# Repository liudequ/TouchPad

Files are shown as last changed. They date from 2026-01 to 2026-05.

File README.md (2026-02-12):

# 仓库指南

## 项目结构与模块组织
这是一个 Arduino 草图集合仓库。所有可编译草图放在 `sketches/` 下，并按 `product/`、`tools/`、`experiments/` 分组，每个草图一个独立文件夹，且 `.ino` 文件名与文件夹名一致：

- `sketches/tools/blink/blink.ino`
- `sketches/tools/ps2_scan/ps2_scan.ino`
- `sketches/tools/hid_report_dump/hid_report_dump.ino`
- `sketches/experiments/two_finger_tuning/two_finger_tuning.ino`
- `sketches/tools/try_read_data/try_read_data.ino`
- `sketches/product/touchpad_hid_nrf/touchpad_hid_nrf.ino`
- `sketches/tools/touchpad_i2c_probe_nrf/touchpad_i2c_probe_nrf.ino`
- `sketches/tools/ble_conn_test/ble_conn_test.ino`
- `sketches/tools/ble_hid_rate_test/ble_hid_rate_test.ino`
- `sketches/tools/serial_alive_nicenano/serial_alive_nicenano.ino`
- `sketches/tools/led_test_nicenano/led_test_nicenano.ino`
- `sketches/tools/soft_switch_test/soft_switch_test.ino`

文档放在 `docs/`（索引见 `docs/README.md`）。每个草图自包含、互不依赖。
3D 模型放在 `models/`，用于外壳设计与打印参考。
制造资料入口见 `manufacturing/README.md`。

## 文档说明（docs）
- `docs/touchpad_usage.md`：nRF 触摸板使用说明（接线、烧录、操作、串口命令与 UI 配置）。
- `docs/arduino_ide_supermini_setup.md`：Arduino IDE 本地板卡配置与 UF2 刷写流程说明。
- `docs/ble_conn_test.md`：`ble_conn_test` 草图的人工测试步骤与预期结果。
- `docs/bluetooth_migration_notes.md`：蓝牙迁移历史记录与现状说明（含 BLE 抓包分析方法）。
- `docs/bom.md`：触摸板项目物料清单（BOM）与接线速查。
- `docs/video_intro_flow.md`：触摸板介绍视频的分段流程与口播参考。
- `docs/stability_tuning.md`：手感稳定性与防抖调参思路清单。
- `docs/fpc_pinout.md`：触摸板 FPC 转接板引脚定义（nRF 方案）。
- `docs/schematic_nice_nano_v2.png`：nice!nano v2 原理图参考图。
- `docs/Promicro NRF52840开发板 兼容nice!nano V2.0 带蓝牙 充电管理-淘宝网.png`：开发板商品页截图参考。
- `docs/nRF52840_PS_v1.1.pdf`：nRF52840 官方规格书（参考资料）。

## 模型说明（models）
- `models/touchpad_case.scad`：触摸板外壳 OpenSCAD 源文件。
- `models/touchpad_case.stl`：触摸板外壳可打印 STL 文件。
- `models/case_notes.md`：外壳设计与打印参数说明。
- 备注：当前 3D 模型较粗糙，主要用于尺寸与装配验证，实际空间有很大的冗余。

## 构建、测试与开发命令
当前推荐流程（nice!nano v2）：

1. 在 Arduino IDE 打开目标草图，执行“导出编译二进制文件”（Export Compiled Binary）。
2. 在仓库根目录运行：
   - `tools/make_uf2_latest_nicenano_v2.sh`
3. 脚本会基于最新导出的二进制生成对应 `.uf2` 文件。
4. 将生成的 `.uf2` 文件复制到开发板暴露的 UF2/U 盘磁盘中完成刷写。

可选：若需要命令行编译，可使用 Arduino CLI：
- `arduino-cli compile --fqbn <board_fqbn> <sketch_path>`

将 `<board_fqbn>` 替换为实际板卡，将 `<sketch_path>` 替换为草图路径（如 `sketches/product/touchpad_hid_nrf`）。

## 代码风格与命名规范
- 采用标准 Arduino C++ 风格：2 空格缩进、K&R 花括号风格、清晰的函数命名。
- 变量命名应具描述性，尽量减少全局变量。
- 草图文件名与其所在目录保持一致（如 `sketches/tools/ps2_scan/ps2_scan.ino`）。
- 触摸板主逻辑改动优先同步更新 `sketches/product/touchpad_hid_nrf` 与相关文档（如 `docs/touchpad_usage.md`）。
- 串口/日志输出尽量使用中文。

## 测试指南
当前无自动化测试。请在目标硬件上编译并上传，使用串口监视器或设备输出验证行为。

## 提交与合并请求规范
本仓库包含 git 历史。建议使用简短、祈使语气的提交信息（例如：“Add I2C scan timeout”）。

提交变更时请包含：
- 受影响草图的简短描述
- 用于验证的板卡/固件环境
- 任何连线或硬件假设
- 提交日志（commit message）使用中文

补充：如果用户未指定提交信息，可由助手根据本次变更自行总结。
补充：执行提交后，默认一并推送到当前远端分支；若用户明确说明不推送，则仅提交不推送。

## 配置提示
部分草图涉及 USB HID 或 I2C/PS2 设备。请确认板卡支持相关接口，并在草图顶部按需调整引脚映射。

## 触摸板代码概览
这是一个触摸板项目。关键草图及职责如下：

- `sketches/product/touchpad_hid_nrf/touchpad_hid_nrf.ino`：nRF 主触摸板实现（I2C-HID 读取 `0x2C`/`0x0109`，单指移动、双指滚动、三指/四指手势、点击/双击、USB/BLE HID 输出、省电分级、配置持久化）。
- `sketches/product/touchpad_hid_nrf/modules/`：触摸板主草图的功能模块拆分（电源/电量、BLE 传输、HID 输出）。
- `sketches/experiments/two_finger_tuning/two_finger_tuning.ino`：触摸到鼠标映射的实验版本，带报文打印，重点是单指/双指的平滑与加速。
- `sketches/tools/hid_report_dump/hid_report_dump.ino`：I2C-HID 报文抓取与十六进制打印，便于理解原始输入帧。
- `sketches/tools/try_read_data/try_read_data.ino`：Goodix 风格寄存器盲读工具（`0x8100`）及状态清理。
- `sketches/tools/touchpad_i2c_probe_nrf/touchpad_i2c_probe_nrf.ino`：nRF 侧 I2C 触摸板探测工具（用于定位触摸控制器地址与连线确认）。

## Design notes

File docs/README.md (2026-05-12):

# 文档索引

## 快速开始
- `touchpad_usage.md`：触摸板接线、烧录、操作、串口命令、UI 配置。
- `arduino_ide_supermini_setup.md`：Arduino IDE 板卡配置与 UF2 流程。
- `bom.md`：物料与接线速查。
- `v2_intro.md`：TouchPad V2 介绍文档与讲解提纲。

## 功能与调参
- `stability_tuning.md`：手感稳定性与防抖参数思路。
- `ble_slot_switch_plan.md`：BLE 三设备切换设计方案。
- `bluetooth_migration_notes.md`：蓝牙迁移记录与抓包分析方法。

## 测试与验证
- `ble_conn_test.md`：`sketches/tools/ble_conn_test` 人工测试步骤。

## 硬件参考
- `fpc_pinout.md`：FPC 转接板引脚定义（含已知问题：PCB 底板 FPC 方向设计反了）。
- `schematic_nice_nano_v2.png`：nice!nano v2 原理图参考。
- `nRF52840_PS_v1.1.pdf`：nRF52840 规格书。
- `Promicro NRF52840开发板 兼容nice!nano V2.0 带蓝牙 充电管理-淘宝网.png`：开发板商品页截图。

## 其它
- `next_optimization_notes.md`：后续硬件优化清单（底板布局、开关形态、FPC 引脚定义）。

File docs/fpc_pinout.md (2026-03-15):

# FPC 转接板针脚定义

## nRF52840 SuperMini / nice!nano v2（当前方案）
- Pin1 VCC -> 3V3
- Pin2 SCL -> D8
- Pin3 SDA -> D9
- Pin4 INT -> D7
- Pin5 ENABLE -> D6
- Pin6 GND -> GND

## 已知问题记录
- 当前文档已按镜像后的实际顺序更新。
- 若继续参考旧版本资料或旧丝印，可能会把 `Pin1~Pin6` 顺序看反，导致触摸板异常（如设备发热、无法通信）。
- 建议：上电前先用万用表逐脚确认 `Pin1~Pin6` 实际对应关系。

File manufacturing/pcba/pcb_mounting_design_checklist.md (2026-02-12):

# 触摸板 PCB 固定设计清单（设计阶段）

适用范围：
- 触摸板底板（`nice!nano v2` 直焊方案）
- 在 PCB 设计阶段，把“与外壳固定”相关风险前置解决

目标：
- 不只做孔位，而是一次性完成：孔位、禁布、装配空间、定位特征、量产约束

---

## 0. 先定固定方案（必须先做）
在开始画孔前，先二选一（或组合）：

1. 螺丝固定：`M2/M2.5 + 立柱（塑料柱/铜螺母）`
2. 非螺丝固定：`导轨/卡扣/胶粘（原型）`

输出物（至少一条）：
- `固定方式`（例如：4 点 M2 螺丝 + 热熔铜螺母）
- `是否可拆`（可维护/一次性）
- `目标板厚`（当前建议 `0.8mm`）

---

## 1. 孔位与板框（核心）
要做的事：
1. 放置安装孔（建议优先 `NPTH` 机械孔）。
2. 确认孔径、孔边到板边距离、孔到元件距离。
3. 与外壳立柱中心坐标逐一对齐。
4. 在板框标出 USB/FPC/按键朝向，避免镜像。

设计建议（起步值）：
- 孔径：`M2` 常用 `2.2mm`（按螺丝与工艺微调）
- 薄板 `0.8mm` 时，孔不要太靠边，避免开裂

本项目建议输出：
- 机械尺寸图（含 4 个安装孔坐标）
- 板框方向图（标出 `USB`、`J1 Pin1`、`SW1`）

---

## 2. 禁布区与装配空间（避免装不上）
要做的事：
1. 对螺丝头、立柱、FPC 锁扣建立机械禁布区（Top/Bottom 都看）。
2. 对 USB 插头插拔路径留空间。
3. 对 FPC 弯折半径和插拔手指空间留余量。
4. 对电池座插头拔插方向做避让。

重点：
- 禁止让高器件进入螺丝头/立柱投影区。
- FPC 方向必须在丝印标清 `Pin1`。

本项目建议输出：
- 一张“禁布示意图”（标注 USB/FPC/电池座三类空间）

---

## 3. 定位与防呆特征（装配效率）
要做的事：
1. 在 PCB 加定位特征：定位缺口/非对称边/止挡边（任选）。
2. 丝印防呆：`TOP`、`Pin1`、`BAT+/-`、`RST`。
3. 若用导轨，定义导轨配合边的尺寸公差。

本项目建议输出：
- “防呆清单”1 页（生产和组装都能直接看懂）

---

## 4. 结构强度与电气协同（防裂、防干扰）
要做的事：
1. 安装孔周围留机械加强区（不要贴太近的开槽/细颈）。
2. 固定金属件附近避开敏感信号（`SDA/SCL/INT/EN`）。
3. 若考虑机壳接地，提前定义机壳地策略（可选）。

注意：
- 当前方案是低速 I2C，重点是稳定与可维护，不需要过度复杂化。

---

## 5. 可制造性（DFM）与下单文件
要做的事：
1. 明确孔类型（`NPTH/PTH`）与板厂能力。
2. DRC/ERC 全通过后再导出生产文件。
3. 下单前做 1:1 打印，实物对位（尤其 USB、FPC、按键）。

导出文件：
- `Gerber`
- `Drill`
- `BOM`
- `CPL`

---

## 6. 下单前最终核对（可直接打勾）
- [ ] 固定方案已定（螺丝/导轨/卡扣/胶）
- [ ] 安装孔孔径、孔位坐标已和外壳立柱对齐
- [ ] 安装孔类型已确认（建议机械孔 `NPTH`）
- [ ] 螺丝头/立柱投影区无器件干涉
- [ ] USB 插拔空间确认
- [ ] FPC 插拔与弯折空间确认
- [ ] `J1 Pin1` 丝印清晰可见
- [ ] `BAT+/-`、`RST`、方向标识完整
- [ ] DRC/ERC 无错误
- [ ] 1:1 打印并与外壳试装

---

## 7. 本仓库配套参考
- 网络连接：`manufacturing/pcba/netlist_nicenano_baseboard.md`
- 器件选型：`manufacturing/pcba/component_selection.md`
- EDA流程：`manufacturing/pcba/jlc_eda_workflow.md`
- FPC定义：`docs/fpc_pinout.md`
- 固件引脚：`sketches/product/touchpad_hid_nrf/touchpad_hid_nrf.ino`

---

## 8. 一步步执行建议（建议按此顺序）
1. 先确定固定方式（今天就定）。
2. 我帮你把安装孔参数和坐标先定稿。
3. 你在 EDA 放孔和画禁布区，我帮你做逐项复核。
4. 通过后再走布线和 DRC，最后导出生产文件。

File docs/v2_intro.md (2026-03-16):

# TouchPad V2 视频口播稿

这份文档是压缩到约 2 分钟的口播版，保留四段结构，适合直接录制。

## 推荐时长

- 总时长：约 2 分钟
- 适合形式：项目介绍、成品展示、视频口播

## 2 分钟口播稿

大家好，这次想介绍一下我做的 TouchPad V2。

它是一块基于 `nRF52840` 的触摸板，支持 `USB HID` 和 `BLE HID` 两种输出方式。基础操作上，它支持单指移动、双指滚动、轻触点击，同时也支持三指和四指手势，并且可以通过串口或者上位机 UI 来做参数和动作映射配置。

如果说前面的版本更像是在验证这个触摸板能不能跑起来，那 V2 更像是一个真正往成品方向推进的版本。因为这一版不只是把功能做通了，还补上了 PCB 底板、外壳，以及比较完整的文档和分享资料。

先说初始总结。V2 的核心目标不是做一个简单演示，而是尽量做成一个日常可用、可调、可复用，也方便别人理解和复现的版本。所以这一版最重要的提升，就是功能、结构和资料三件事开始连成闭环了。

接下来是 PCB 板介绍。V2 的 PCB 主要解决的是稳定连接、规整装配和方便复现这三个问题。当前方案基于 `nice!nano v2` 或者 `SuperMini nRF52840`，触摸板这一侧使用 `6P 1.0mm` FPC 接口，固件按 `I2C-HID` 方式读取，设备地址是 `0x2C`。这块板子的意义，不是电路多复杂，而是把原来飞线和临时接法，整理成了一块更稳定、更容易装配、也更适合分享的底板。

然后是外壳介绍。V2 现在已经配套了外壳模型，说明这个项目已经不只是电路和固件验证，而是开始认真处理整机形态。当然它现在还更偏工程验证版本，不是最终外观版，但它已经能把触摸板、PCB、主控和电池稳定装进同一套空间里，让这个项目从电子模块，变成一个真正可以拿在手里展示和使用的设备。

最后是 PCB 板分享。V2 现在已经整理出了比较完整的分享资料，包括 `Gerber` 生产文件、PCB 的 `STEP` 模型、外壳文件、BOM、FPC 引脚定义，以及固件烧录和使用说明。也就是说，分享出去的不只是“一张板子的截图”，而是一套别人可以看懂、可以组装、也可以继续修改的版本。

总结一下，TouchPad V2 的意义，不只是把触摸板跑起来，而是把 PCB、外壳、固件和文档慢慢整理成了一套完整方案。它还不是最终版，但已经从实验验证，走到了一个更接近成品、也更适合分享的阶段。

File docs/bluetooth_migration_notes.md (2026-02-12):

# 蓝牙改造记录（历史）

> 说明：本文件主要保留迁移过程记录；当前实现以 `sketches/product/touchpad_hid_nrf/touchpad_hid_nrf.ino` 为准。

## 目标
将触摸板迁移到 nRF52840，实现 BLE HID，并保留 USB 使用路径。

## 已落地现状（当前）
- 触摸板 I2C 读取已接入（含 INT 触发读取与 TP_EN 时序）。
- 手势映射已接入：单指移动、双指滚动、三指滑动、四角区域动作。
- 输出层已支持 USB HID + BLE HID。
- 连接管理已包含广播、连接/断开回调、清配对（`PAIRCLR`）。
- 配置存储已接入（板载文件系统）。
- 配置通道当前以 USB 串口为主（UI 侧 BLE 调参已移除）。
- 省电策略已包含空闲分级与相关配置项（`bleIdle*`、`lightIdleRate`）。

## 迁移期间关键结论（保留）
- nRF52840 生态成熟，BLE HID 实用性较好。

## 硬件与功耗备忘
- 可利用 `PIN_EXT_VCC` / `EXT_VCC`（不同变体命名可能不同）控制外设供电。
- 板载 LED 可用于连接/省电状态指示。
- 完全断电策略会影响唤醒与连接时延，需按续航目标取舍。

## BLE 抓包与上报频率分析（保留）
用于评估 BLE HID 实际上报频率。

### btmon + Wireshark
1. `sudo btmon -w /tmp/ble.btsnoop`
2. 连接触摸板并操作 10-20 秒。
3. 停止抓包。
4. 用 Wireshark 打开 `/tmp/ble.btsnoop`。
5. 过滤：`btatt.opcode == 0x1b`

### 命令行计算平均间隔
```bash
tshark -r /tmp/ble.btsnoop -Y 'btatt.opcode==0x1b' -T fields -e frame.time_delta_displayed \
| awk '{sum+=$1; n++} END {if(n>0) printf("avg=%.6f s, freq=%.2f Hz\\n", sum/n, 1/(sum/n))}'
```

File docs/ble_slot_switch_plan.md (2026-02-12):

# BLE 三设备切换实现思路（触摸板）

## 目标
- 支持在 3 台已配对设备之间快速切换连接。
- 任意时刻仅保持 1 条 BLE HID 连接（避免多连接带来的带宽与复杂度问题）。
- 连接切换后尽快恢复输入可用。

## 推荐方案
采用“3 槽位配对 + 单连接快速切换”：

1. 固件维护 `slot1/slot2/slot3` 三个槽位。
2. 当前连接绑定到一个 `activeSlot`。
3. 用户触发切换后：
   - 断开当前连接；
   - 进入目标槽位重连流程；
   - 成功后更新当前状态。

## 状态机建议
1. `ACTIVE(slotN)`：正常工作状态。
2. `SWITCHING`：收到切换请求。
3. `DISCONNECT_CURRENT`：主动断开当前主机。
4. `RECONNECT_SLOT_N`：按目标槽位进行广播/重连。
5. `TIMEOUT_FALLBACK`：超时后回退（通用广播或返回上一个槽位）。

## 关键实现点
1. 槽位管理
- 增加配置项：`activeSlot(1..3)`、每槽位是否已绑定。
- 复用现有 `InternalFS` 进行持久化。

2. 切换触发
- 优先使用串口命令验证：`SLOT 1|2|3`。
- 稳定后再绑定手势（例如四指左右滑循环切槽）。

3. 连接策略
- 切槽时先断开当前连接。
- 启动目标槽位重连窗口（建议 8~15 秒快速广播）。
- 目标槽位未绑定时进入该槽位配对模式。

4. 绑定与清理
- 支持按槽位管理配对：`PAIR SLOT n`、`UNPAIR SLOT n`。
- 保留总清除：`PAIRCLR`。

5. 状态反馈
- LED 区分槽位状态（例如不同闪烁节奏表示 slot1/2/3）。
- 串口 `GET` 增加状态输出：`activeSlot`、`slot1/2/3 bonded`、`connectedSlot`。

## 落地顺序（建议）
1. 先实现串口切槽与状态查询（不改手势）。
2. 再接入槽位绑定状态持久化。
3. 最后增加手势触发切槽。

## 当前项目中的最小可用版本（MVP）
第一阶段仅做：
- `SLOT n` 切换命令；
- 当前槽位状态查询；
- LED/串口可见反馈；
- 保持现有 HID 主逻辑不变。

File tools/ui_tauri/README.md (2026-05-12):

# Touchpad Config UI (Tauri)

这是 `tools/ui_tauri/` 下的 Tauri 版触摸板配置工具：

- USB 串口连接/断开
- 读取当前配置（`GET`）
- 应用配置（批量 `SET ...`）
- `SAVE` / `LOAD` / `RESET`
- 区域和三/四指手势绑定
- 快捷键录制（modifier + HID keycode）

## 目录结构

- `src/`：前端页面（原生 HTML/CSS/JS）
- `src-tauri/`：Rust 后端（串口桥接 + Tauri 壳）

## 本地开发

在仓库根目录执行：

```bash
cd tools/ui_tauri
npm install
npm run dev
```

说明：
- `npm run dev` 会启动 Tauri 开发窗口。
- 当前实现使用 USB 串口调参，不使用 BLE 调参。

## 打包

```bash
cd tools/ui_tauri
npm run build
```

打包产物会在 `tools/ui_tauri/src-tauri/target/release/bundle/` 下（按平台生成）。

## 平台注意事项

- macOS：建议签名 + notarization，否则用户首次运行会被 Gatekeeper 拦截。
- Linux：可能需要串口权限（例如把用户加入 `dialout` 组）。
- Windows：通常可直接安装使用。

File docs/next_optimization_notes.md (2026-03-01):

# 后续可优化内容记录

## 结构与器件优化
1. 底板上 nRF 开发板位置可进一步向前移动，优化整体布局与装配空间。
2. 轻触开关建议更换为卧式封装，提升安装便利性与结构匹配。
3. FPC 转接组件引脚定义需调整为 1~6 号反转，底板走线与丝印也需同步调整，避免方向冲突。

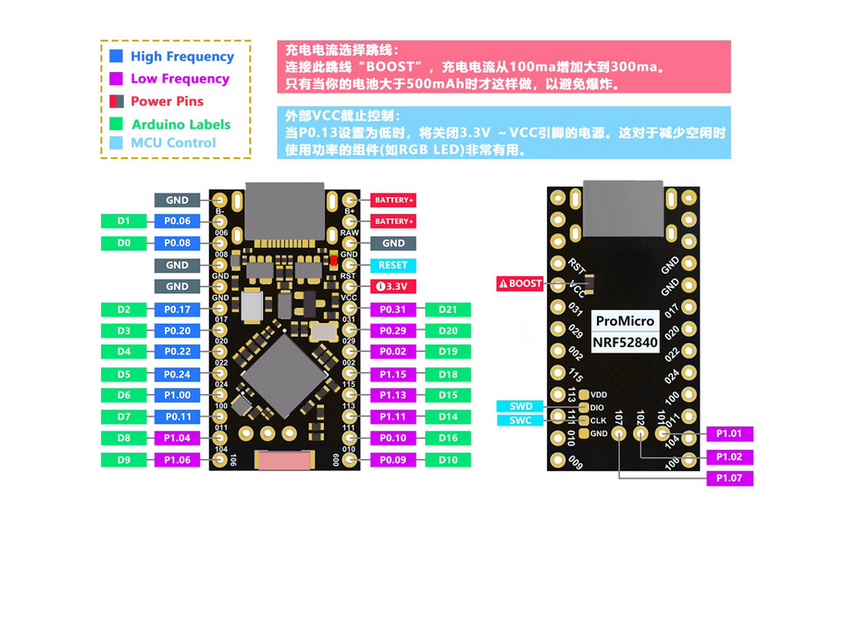
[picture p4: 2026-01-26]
docs/Promicro NRF52840开发板 兼容nice!nano V2.0 带蓝牙 充电管理-淘宝网.png

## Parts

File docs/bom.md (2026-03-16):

# 触摸板项目 BOM 清单

## 必需元件
| 类别 | 名称 | 规格/示例 | 数量 | 备注 |
|---|---|---|---:|---|
| 主控 | nRF52840 开发板 | nice!nano v2 / SuperMini nRF52840 | 1 | 负责 I2C 读取与 USB/BLE HID 输出 |
| 触摸输入 | 触摸板模组 | I2C-HID，地址 `0x2C` | 1 | 需有 `SDA/SCL/INT/EN` 引脚；关键词：SP1197T触摸板 |
| 供电 | LiPo 电池 | `800mAh`，型号 `403450` | 1 | 设备内置供电电池 |
| 接插件 | 电池连接器 | `2P / 卧贴 / MX1.25` | 1 | 用于连接电池 |
| 连接 | FPC 连接器座 | `6P / 1.0mm / 翻盖下接` | 1 | 用于连接触摸板 FPC 软排线 |
| 连接 | FPC 软排线 | 6P，1.0mm 间距，长度 `5cm` | 1 | 用于连接触摸板；备注：同向6P |
| 开关 | 二脚轻触开关 | `6*6*4.3` | 1 | 用于开机/控制输入 |
| 辅材 | 脚垫 | `10mm*3mm` | 4 | 用于外壳底部防滑与抬高 |
| 数据/供电 | USB 线 | Type-C | 1 | 刷机、供电、串口调试 |
| 结构 | 外壳模型 | `models/外壳-盒体.stl` | 1 | 外壳打印文件 |
| 制造 | PCB 生产文件 | `models/Gerber_PCB.zip` | 1 | 用于板厂下单生产 |

## 连接速查
- 触摸板 `VCC` -> 主控 `3V3`
- 触摸板 `GND` -> 主控 `GND`
- 触摸板 `SDA` -> 主控 `D9`
- 触摸板 `SCL` -> 主控 `D8`
- 触摸板 `INT` -> 主控 `D7`
- 触摸板 `EN` -> 主控 `D6`
- 微动复位（可选）：微动开关两端分别接主控 `RST` 与 `GND`，按下时短接触发复位。

## FPC 针脚速查（镜像后的当前定义）
- `Pin1` -> `VCC` -> 主控 `3V3`
- `Pin2` -> `SCL` -> 主控 `D8`
- `Pin3` -> `SDA` -> 主控 `D9`
- `Pin4` -> `INT` -> 主控 `D7`
- `Pin5` -> `ENABLE/EN` -> 主控 `D6`
- `Pin6` -> `GND` -> 主控 `GND`

注意：这里的 `Pin1~Pin6` 已按镜像后的实际顺序整理，不要再按旧丝印理解。

详见：`docs/fpc_pinout.md`。

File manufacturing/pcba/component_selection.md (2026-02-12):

# 触摸板底板器件选型记录

记录日期：2026-02-09

## 已确认 LCSC 编号
- FPC 底座（6P, 1.0mm）：`C51901510`
- 电池座（2Pin）：`C53055318`
- 复位微动开关（3x6x4.3）：`C231711`

## 备注
- 以上编号用于嘉立创EDA/SMT选型对齐。
- 下单前需再次核对：FPC 上下接、同向/反向、器件高度。

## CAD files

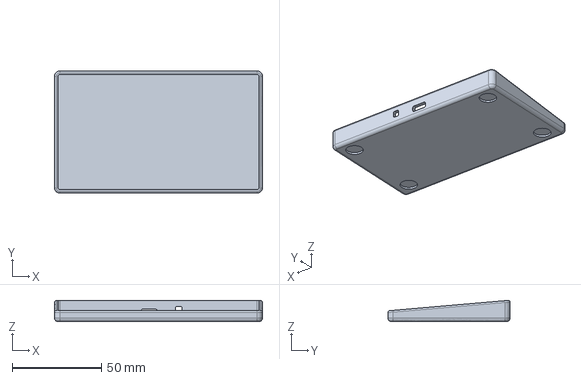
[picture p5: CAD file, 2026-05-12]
models/外壳.FCStd
116.5 x 68.5 x 11.9 mm

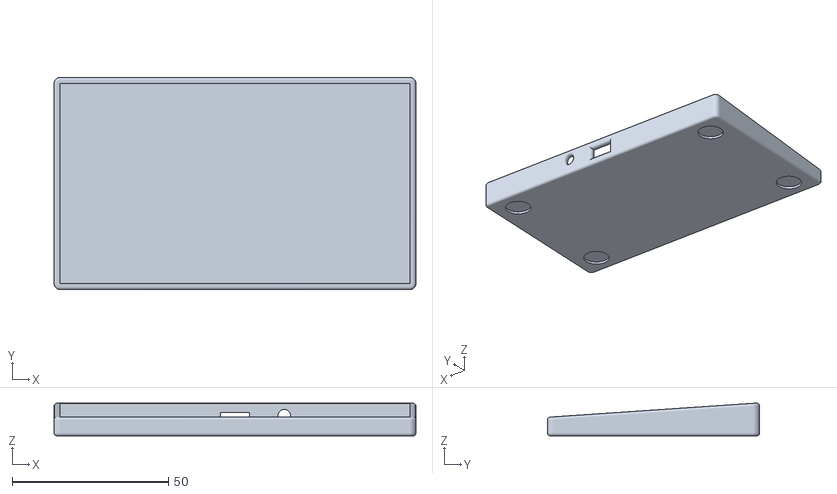
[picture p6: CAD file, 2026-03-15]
models/外壳-盒体.stl
116.0 x 68.0 x 10.5

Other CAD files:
models/外壳-Body001.3mf
models/外壳-Body001.stl

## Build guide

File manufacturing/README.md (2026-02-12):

# 制造资料入口

本仓库制造相关资料当前集中在 `manufacturing/pcba/`。

## PCB/PCBA 资料
- `manufacturing/pcba/jlc_eda_workflow.md`：JLC EDA 设计流程与检查项。
- `manufacturing/pcba/netlist_nicenano_baseboard.md`：底板网表定义。
- `manufacturing/pcba/component_selection.md`：器件选型参考。
- `manufacturing/pcba/pcba_minimal_height_nicenano.md`：PCBA 高度约束说明。
- `manufacturing/pcba/pcb_mounting_design_checklist.md`：固定设计清单。
- `manufacturing/pcba/easyeda_pro_lib/`：EasyEDA Pro 导入资料。

## 外壳与结构
- `models/touchpad_case.scad`：外壳 OpenSCAD 源文件。
- `models/touchpad_case.stl`：可打印 STL。
- `models/case_notes.md`：打印与装配说明。

## 关联文档
- `docs/bom.md`：BOM 与接线速查。
- `docs/fpc_pinout.md`：FPC 引脚定义。

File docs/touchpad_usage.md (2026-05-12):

# 触摸板使用说明（nRF 版）

本项目将触摸板输入转换为 HID 输入设备输出，支持 USB 与 BLE。

## 硬件连接（nice!nano v2 / SuperMini nRF52840）
- 触摸板供电：`VCC=3V3`、`GND=GND`
- 触摸板 I2C：`SDA=D9`、`SCL=D8`
- 中断引脚：`INT=D7`（上拉输入）
- 使能引脚：`TP_EN=D6`
- 设备 I2C 地址：`0x2C`
- 若通过 FPC 转接板接线，当前针脚顺序按镜像后的实际定义，详见 `docs/fpc_pinout.md`。

如需修改引脚或地址，编辑 `sketches/product/touchpad_hid_nrf/touchpad_hid_nrf.ino` 顶部宏定义。
物料清单见 `docs/bom.md`。

## 固件烧录流程（推荐）
1. 在 Arduino IDE 中打开 `sketches/product/touchpad_hid_nrf/touchpad_hid_nrf.ino`。
2. 选择板卡与串口，执行“导出编译二进制文件”（Export Compiled Binary）。
3. 在仓库根目录运行：
   ```bash
   tools/make_uf2_latest_nicenano_v2.sh
   ```
4. 将生成的 `.uf2` 文件复制到开发板挂载出的 UF2/U 盘中完成刷写。

## 操作方式
- 单指滑动：移动鼠标指针。
- 双指上下滑动：滚轮滚动。
- 单指轻触抬起：单击。
- 双击：在时间窗口内连续两次轻触抬起。
- 左上角轻触：后退（默认 Alt+Left）。
- 右上角轻触：前进（默认 Alt+Right）。
- 右下角轻触：右键（默认）。
- 左下角轻触：默认未绑定，可在配置中自定义。
- 三指左右/上下滑动：触发配置绑定动作。
- 三指单击/双击：触发配置绑定动作。
- 四指左右/上下滑动：触发配置绑定动作。
- 四指单击/双击：触发配置绑定动作。

## 区域说明
当前区域划分为上边 `20%` 高度、左右各 `35%` 宽度。
- 左上角区域：后退
- 右上角区域：前进
- 右下角区域：右键
- 左下角区域：默认不启用

可通过参数 `topZonePercent`、`sideZonePercent`、`enableNavZones` 调整。

## 串口配置（当前固件）
固件支持串口命令配置并持久化到板载文件系统。

常用命令：
```text
HELP
GET
GET <key>
GET battery
GET slot
INFO SLOT
SET <key> <value>
SLOT <1|2|3>
PAIR SLOT <1|2|3>
PAIR SLOT <1|2|3> FORCE
UNPAIR SLOT <1|2|3>
SAVE
LOAD
RESET
PAIRCLR
```

常见参数：
- 移动/滚动：`sensitivity`、`smoothFactor`、`accelFactor`、`maxAccel`、`maxDelta`、`moveDeadband`、`scrollSensitivity`
- 区域：`topZonePercent`、`sideZonePercent`、`enableNavZones`
- 四角动作：`leftTop*`、`rightTop*`、`rightBottom*`、`leftBottom*`
- 三指动作：`threeLeft*`、`threeRight*`、`threeUp*`、`threeDown*`
- 三指点击：`threeTap*`、`threeDoubleTap*`
- 三指阈值：`threeSwipeThresholdX`、`threeSwipeThresholdY`、`threeSwipeTimeout`、`threeSwipeCooldown`
- 四指动作：`fourLeft*`、`fourRight*`、`fourUp*`、`fourDown*`、`fourTap*`、`fourDoubleTap*`
- 四指阈值：`fourSwipeThresholdX`、`fourSwipeThresholdY`、`fourSwipeTimeout`、`fourSwipeCooldown`
- 连接/省电：`useBleWhenUsb`、`bleIdleSleepEnabled`、`bleIdleLightMs`、`bleIdleMediumMs`、`bleIdleSleepMs`、`lightIdleRate`
- 槽位管理：`slotManagerEnabled`、`GET slot`、`INFO SLOT`、`SLOT n`、`PAIR SLOT n`、`PAIR SLOT n FORCE`、`UNPAIR SLOT n`
- 电量查询：`GET battery`（返回 `batteryMv` 与 `battery` 百分比）

槽位覆盖说明：
- 当目标槽位已有绑定时，执行 `PAIR SLOT n` 会返回确认提示，不会直接覆盖。
- 确认覆盖请使用：`PAIR SLOT n FORCE`。

## 三阶段省电策略
当 `bleIdleSleepEnabled=1` 且使用 BLE 传输时，固件会按空闲时长进入三阶段省电：

1. 第一阶段（轻度空闲）  
触发条件：空闲时长 >= `bleIdleLightMs`  
行为：进入轻度省电状态，降低活跃度并按 `lightIdleRate` 控制上报节奏。

2. 第二阶段（中度空闲）  
触发条件：空闲时长 >= `bleIdleMediumMs`  
行为：进入更深一层省电状态，断开当前 BLE 连接并停止广播。

3. 第三阶段（深度空闲）  
触发条件：空闲时长 >= `bleIdleSleepMs`  
行为：进入深度睡眠，进一步降低功耗，等待唤醒。

说明：
- 阈值需满足：`bleIdleLightMs < bleIdleMediumMs < bleIdleSleepMs`。固件会在内部做最小间隔校正。
- 任意新的触摸操作会更新活动时间并退出空闲阶段，恢复正常工作状态。

区域类型可选值：`NONE`、`MOUSE`、`KEYBOARD`。

常用修饰键位掩码（可组合）：`CTRL=1`、`SHIFT=2`、`ALT=4`、`GUI=8`。
常用按键码示例：`RIGHT=79`、`LEFT=80`、`DOWN=81`、`UP=82`。

示例：
```text
GET
SET scrollSensitivity 0.00002
SET leftBottomType MOUSE
SET leftBottomButtons 2
SET threeLeftType KEYBOARD
SET threeLeftModifier 5
SET threeLeftKey 80
SET sideZonePercent 35
SAVE
```

## 上位机 UI（Tauri）
可使用 `tools/ui_tauri` 图形化配置。

本地开发：
```bash
cd tools/ui_tauri
npm install
npm run dev
```

打包：
```bash
cd tools/ui_tauri
npm run build
```

说明：
- 当前 nRF 固件使用 USB 串口调参，不使用 BLE 调参。
- Windows、macOS、Linux 打包产物位置见 `tools/ui_tauri/README.md`。

## 串口权限（Linux）
首次在新机器连接时，若遇到 `/dev/ttyACM0` 权限不足，可将当前用户加入 `dialout` 组：

```bash
groups
sudo usermod -aG dialout $USER
```

执行后注销并重新登录。

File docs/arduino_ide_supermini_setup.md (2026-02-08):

# Arduino IDE 使用 SuperMini nRF52840 的本地板卡配置

为解决 Arduino IDE 2.3.7 在选择 `nRFMicro-like Boards` 时无法生效的问题，
改用本地 `hardware/` 目录加载板卡核心。

## 步骤
1. 将板卡核心放到仓库内的本地硬件目录：
   ```text
   /home/liudq/Work/TouchPad/hardware/pdcook/nrf52
   ```
2. 打开 Arduino IDE -> Preferences -> Sketchbook Location，设置为：
   ```text
   /home/liudq/Work/TouchPad
   ```
3. 重启 Arduino IDE。
4. 在 Tools -> Board 中选择：
   ```text
   pdcook -> SuperMini nRF52840
   ```

## 说明
- 使用本地 `hardware/` 后，IDE 不再依赖 Boards Manager 中的 `nRFMicro-like Boards` 包。
- 该方式适用于包名包含空格导致 FQBN 解析异常的情况。

## UF2 刷写流程（推荐）
1. 在 Arduino IDE 中执行“导出编译二进制文件”（Export Compiled Binary）。
2. 在仓库根目录执行：
   ```bash
   tools/make_uf2_latest_nicenano_v2.sh
   ```
3. 将生成的 `.uf2` 文件拷贝到开发板挂载出的 `NICENANO` 盘。

## 备用：手动 uf2conv
如需手动转换，可执行：

```bash
python3 hardware/pdcook/nrf52/tools/uf2conv/uf2conv.py -c -f 0xADA52840 -o your_firmware.uf2 your_firmware.hex
cp your_firmware.uf2 /media/$USER/NICENANO/
```

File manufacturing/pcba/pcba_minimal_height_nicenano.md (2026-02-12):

# 触摸板半一体化 PCBA 清单（高度优先，最简版）

适用范围：
- 保留 `nice!nano v2` 模块
- 追求低高度
- 去掉稳定性增强件（上拉/ESD/电池保护）
- 去掉机械固定件（螺丝/铜柱/胶）

## PCBA BOM（每台）
| 序号 | 类别 | 名称 | 规格 | 数量/台 | 备注 |
|---|---|---|---|---:|---|
| 1 | PCB | 主板裸板 | FR4，`0.8mm`，2层 | 1 | 薄型优先 |
| 2 | 主控 | `nice!nano v2` 模块 | Pro Micro 兼容引脚 | 1 | 直焊到底板 |
| 3 | 连接器 | FPC 底座 | `6P, 1.0mm pitch` | 1 | 与现有触摸板/FPC匹配 |
| 4 | 连接器 | 电池座 | `2Pin` 低矮型号 | 1 | 使用电池供电时装 |
| 5 | 开关 | 复位微动开关 | `6*6*4.3` | 1 | 一端接 `RST`，一端接 `GND`，按下短接复位 |

## 说明
- FPC 排线和电池本体不计入本 PCBA 清单（作为整机来料管理）。
- 触摸板接口沿用当前定义：`VCC/SCL/SDA/INT/EN/GND`。

## 非BOM建议（可选）
- 在PCB上预留测试焊盘：`3V3/GND/SDA/SCL/INT/EN`。

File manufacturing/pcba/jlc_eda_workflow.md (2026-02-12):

# 触摸板底板（nice!nano 直焊）嘉立创EDA完整操作流程

适用范围：
- 半一体化底板
- `nice!nano v2` 直焊
- FPC `6P 1.0mm`
- 电池座 `2Pin`
- 复位微动开关 `3x6x4.3`

相关输入文件：
- `manufacturing/pcba/netlist_nicenano_baseboard.md`
- `manufacturing/pcba/pcba_minimal_height_nicenano.md`
- `manufacturing/pcba/component_selection.md`

---

## 1. 开始前准备（10分钟）
1. 确认网络连接表（Netlist）不再改动。
2. 确认 LCSC 编号：
   - FPC：`C51901510`
   - 电池座：`C53055318`
   - 复位开关：`C231711`
3. 准备好 `nice!nano v2` 实物，拍清晰正反面引脚图（用于核对 BAT/RST/3V3/D6/D7/D8/D9）。
4. 明确外壳约束：USB 方向、限高、板子大概长宽。

---

## 2. 新建EDA工程
1. 打开嘉立创EDA，创建新工程：`touchpad_baseboard`。
2. 先画原理图，不要直接画PCB。

---

## 3. 画原理图（按 Netlist 抄，不自行扩展）

### 3.1 放置器件
1. 放置 `U1`：nice!nano 对应符号（若无现成符号，先用自建连接器符号代替双排引脚）。
2. 放置 `J1`：FPC 6P 1.0mm（对应 `C51901510` 的符号/封装）。
3. 放置 `BT1`：电池座 2Pin（对应 `C53055318`）。
4. 放置 `SW1`：轻触开关 2Pin（对应 `C231711`）。

### 3.2 连线（必须与 netlist 一致）
1. `J1.1 -> GND -> U1.GND`
2. `J1.2 -> TP_EN -> U1.D9`
3. `J1.3 -> TP_INT -> U1.D8`
4. `J1.4 -> I2C_SDA -> U1.D7`
5. `J1.5 -> I2C_SCL -> U1.D6`
6. `J1.6 -> TP_3V3 -> U1.3V3`
7. `SW1.1 -> RST_N -> U1.RST`
8. `SW1.2 -> GND`
9. `BT1.1 -> GND`
10. `BT1.2 -> BAT_POS -> U1.BAT`

### 3.3 标注和检查
1. 添加网络标签：`GND/TP_3V3/I2C_SDA/I2C_SCL/TP_INT/TP_EN/RST_N/BAT_POS/BAT_NEG`。
2. 在 `J1` 旁加文字：`Pin1=GND ... Pin6=3V3`。
3. 运行 ERC，消除错误（警告可先记录）。

---

## 4. 转PCB并布局

### 4.1 PCB基础设置
1. 板厚目标：`0.8mm`（在下单参数里设置）。
2. 层数：2层。
3. 线宽建议起步：`0.2mm`；电源线可 `0.3~0.5mm`。
4. 地线尽量连续，最后铺铜 `GND`。

### 4.2 摆位顺序（先机械后电气）
1. 先放 `J1(FPC)`：按排线插入方向放在板边，确保可插拔。
2. 放 `BT1`：靠近外壳开口侧，预留插拔空间。
3. 放 `SW1`：与外壳按键孔对齐。
4. 最后放 `U1(nice!nano)`：保证 USB 方向与外壳开孔一致。

### 4.3 布线优先级
1. 先布 `I2C_SDA/I2C_SCL/TP_INT/TP_EN`。
2. 再布 `3V3/GND/BAT`。
3. 最后铺地铜并复查回流路径。

---

## 5. 必做检查（下单前）
1. `FPC方向`：上接/下接、同向/反向是否与触摸板排线一致。
2. `Pin1标识`：J1 丝印必须可见。
3. `电池极性`：BT1 `+/-` 丝印明确。
   - 当前定义：`BT1-1=GND`、`BT1-2=BAT`；若 BT1 引脚映射改动，电池插头线序（红/黑）必须同步调整。
4. `U1引脚`：`BAT/RST/3V3/D6/D7/D8/D9` 与实物丝印一致。
5. `机械干涉`：FPC锁扣、电池插头、USB 不顶壳。
6. 运行 DRC，无错误再导出。

---

## 6. 导出生产文件
1. 导出 `Gerber`。
2. 导出钻孔文件（Drill）。
3. 导出 `BOM`。
4. 导出 `CPL/坐标文件`。
5. 打包归档：
   - `touchpad_baseboard_gerber.zip`
   - `touchpad_baseboard_bom.csv`
   - `touchpad_baseboard_cpl.csv`

---

## 7. 下单建议（先小批）
1. 先做 `5~10` 套 EVT，不直接 50 套。
2. 首版建议先只让厂家贴 `J1/BT1/SW1`。
3. `nice!nano` 可先人工直焊验证，再决定是否交由工厂工艺处理。

---

## 8. 首板回板验收清单
1. 上电无短路（3V3-GND）。
2. I2C 能识别触摸板地址 `0x2C`。
3. 单指移动、双指滚动、点击正常。
4. 复位键功能正常。
5. 电池供电与充电路径正常（若装电池）。

---

## 9. 常见错误速查
1. 触摸板无响应：FPC 方向错（最常见）。
2. 识别不稳定：SDA/SCL 交叉或虚焊。
3. 无法复位：SW1 接错到非 RST。
4. 电池不工作：BAT 极性反接或接到错误引脚。

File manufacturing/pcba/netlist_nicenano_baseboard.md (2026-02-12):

# TouchPad 半一体化底板 Netlist

适用方案：
- `nice!nano v2` 直焊
- FPC 底座 `6P, 1.0mm`
- 电池座 `2Pin`
- 复位微动开关 `3x6x4.3`

## 网络连接表
| 网络名 | 连接点A | 连接点B |
|---|---|---|
| `GND` | `J1-1 (FPC Pin1)` | `U1-GND` |
| `TP_VCC_3V3` | `J1-6 (FPC Pin6)` | `U1-3V3` |
| `I2C_SDA` | `J1-4 (FPC Pin4)` | `U1-D7` |
| `I2C_SCL` | `J1-5 (FPC Pin5)` | `U1-D6` |
| `TP_INT` | `J1-3 (FPC Pin3)` | `U1-D8` |
| `TP_EN` | `J1-2 (FPC Pin2)` | `U1-D9` |
| `RST_BTN` | `SW1-1` | `U1-RST` |
| `RST_BTN_GND` | `SW1-2` | `U1-GND` |
| `BAT_NEG` | `BT1-1` | `U1-GND` |
| `BAT_POS` | `BT1-2` | `U1-BAT` |

## 器件位号建议
- `U1`: nice!nano v2
- `J1`: FPC 底座（6P, 1.0mm）
- `BT1`: 电池座（2Pin）
- `SW1`: 复位微动开关（3x6x4.3）

## FPC 引脚定义（按当前文档）
- Pin1 = GND
- Pin2 = EN
- Pin3 = INT
- Pin4 = SDA
- Pin5 = SCL
- Pin6 = VCC(3V3)

## 注意事项
- `U1-BAT` 请按你手上 `nice!nano v2` 实物丝印确认（可能标注为 `BAT`/`VBAT`/`B+`）。
- 原理图与PCB中必须标清 `J1 Pin1` 方向，避免 FPC 方向装反。
- 当前电池座定义为：`BT1-1=GND`、`BT1-2=BAT`。若更改 BT1 引脚映射，电池插头线序（红/黑）也必须同步调整，避免反接。

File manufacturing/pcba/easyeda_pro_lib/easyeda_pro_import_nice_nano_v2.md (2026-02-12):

# 嘉立创EDA专业版导入（nice!nano v2 2x13）

已生成可导入压缩包：

- `exports/easyeda_pro_nice_nano_v2_import.zip`

包内内容：

- `easyeda_pro_nice_nano_v2/nice_nano_v2.kicad_sym`
- `easyeda_pro_nice_nano_v2/nice_nano_v2.pretty/NICE_NANO_V2_2X13_P2.54MM.kicad_mod`

## 在嘉立创EDA专业版导入

1. 打开专业版工程。  
2. 进入“库管理/我的库”里的“导入”功能。  
3. 导入符号：选择 `nice_nano_v2.kicad_sym`。  
4. 导入封装：选择 `NICE_NANO_V2_2X13_P2.54MM.kicad_mod`（也可直接选整个 `nice_nano_v2.pretty` 目录）。  
5. 在原理图放置符号后，检查封装关联为 `NICE_NANO_V2_2X13_P2.54MM`。  
6. 同步到PCB后确认：
   - USB 朝向（顶部）
   - Pin1 方向（左上角）
   - 实物孔距一致

## 说明

- 这是按侧边排针 `2x13` 建的模块封装。  
- `D18/D19/D20`（底部额外焊盘）不在这个 `2x13` 封装里。  
- 建议首板前先 1:1 打印对孔，避免镜像错误。

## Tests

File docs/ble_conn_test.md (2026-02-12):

# BLE 连接测试

这是 `sketches/tools/ble_conn_test/ble_conn_test.ino` 在 nRF52840 上的人工测试用例
（兼容 nice!nano v2.0）。

## 前置条件
- 开发板：Pro Micro nRF52840（兼容 nice!nano v2.0）
- 已安装 Arduino core + Adafruit Bluefruit nRF52
- 可用串口监视器（115200 波特率）
- 一台可连接 BLE HID + BLE UART 的手机或电脑

## 测试用例：BLE 连接 + HID/UART
1) 编译并上传 `sketches/tools/ble_conn_test` 到开发板。
2) 打开串口监视器，波特率 115200。
3) 确认日志出现：`[ble] nRF52 BLE connection test`。
4) 在手机/电脑上扫描 BLE 设备并连接 `TouchPadTest`。
5) 确认串口输出 `[ble] connected`。
6) 在串口监视器发送 `INFO`，确认状态显示已连接且带 RSSI。
7) 发送 `HID CLICK`，确认主机收到一次左键点击。
8) 发送 `HID MOVE 20 -10`，确认鼠标光标移动。
9) 若有 BLE UART App，发送 `UART hello`，确认 App 接收到 `hello`。
10) 从主机断开，确认串口输出 `[ble] disconnected`。

## 预期结果
- 设备以 `TouchPadTest` 名称广播。
- 串口能看到连接/断开日志。
- HID 点击/移动能被主机接收。
- BLE UART 在连接状态下能发送文本。

## 备注
- 若配对异常，可在串口监视器发送 `PAIRCLR` 清除配对记录。
- 若主机未显示 HID，请删除配对并重新连接。

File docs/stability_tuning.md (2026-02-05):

# 稳定性与防抖优化清单（待逐步实施）

目标：提升触摸板手感稳定性，降低抖动/漂移，保证输出节拍一致。

## 1) 输入层：坐标低通滤波
- 对原始坐标做一阶 IIR 低通（如 `x_f = x_f + a*(x - x_f)`）。
- 作用：压掉传感器噪声，减少后续算法的抖动放大。
- 建议先在单指路径落地，验证后再应用到双指/三指。

## 2) 运动层：速度/加速限幅
- 在 `MAX_DELTA` 基础上增加速度上限或加速度变化限幅。
- 作用：防止偶发尖峰导致光标跳变。

## 3) 手势层：模式切换滞回
- 单指/双指/三指切换引入 1–2 帧滞回或时间阈值。
- 作用：避免在边缘状态来回抖动导致误切换。

## 4) 输出层：累积量上限
- 对 `accumX/Y`、`accumScroll` 设置上限，避免长时间抖动后“突然跳”。
- 作用：限制最坏情况位移，改善主观稳定性。

## 5) 滚动微动抑制
- 对 `scrollVel` 加静止阈值，小于阈值直接归零。
- 作用：消除细微抖动引起的“慢滚”。

## 6) I2C 读异常恢复
- 读失败累计次数后重置 I2C 或重新初始化触摸板。
- 作用：避免读卡死导致节拍抖动或输入断流。

## 实施顺序建议
1) 输入层低通滤波  
2) 输出层累积上限  
3) 滚动微动抑制  
4) 模式切换滞回  
5) 速度/加速限幅  
6) I2C 异常恢复

---

## 轨迹贴近真实手指路径的做法
- 关闭或弱化加速：`accelFactor = 0`，`maxAccel = 1` 或小幅度加速。
- 降低/关闭死区：`MOVE_DEADBAND` 尽量小。
- 合理放宽限幅：`MAX_DELTA` 不要过低，避免“断笔感”。
- 提高输出频率：从 60 Hz 提升到 90/125 Hz（需评估功耗与 BLE 能力）。
- 低通滤波系数调小：更平滑但会引入轻微延迟，需权衡。

## 与稳定性优化的冲突点
- 加速（稳定手感）会扭曲慢速轨迹形状，影响“画圆像圆”。
- 死区（抑抖）会让小幅度运动变成分段，产生棱角。
- 过强限幅会导致轨迹断裂或变成多段直线。

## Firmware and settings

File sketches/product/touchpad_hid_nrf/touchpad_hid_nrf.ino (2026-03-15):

#include "touchpad_types.h"

#include <Wire.h>
#include <Adafruit_LittleFS.h>
#include <InternalFileSystem.h>
#include <Adafruit_TinyUSB.h>
#include <bluefruit.h>
#include <stdio.h>
#include <string.h>
#if defined(ARDUINO_ARCH_NRF52)
#include <nrf.h>
#include <nrf_gpio.h>
#endif

/*===== I2C-HID =====*/
#define I2C_ADDR 0x2C
#define INPUT_REG_L 0x09
#define INPUT_REG_H 0x01

// nice!nano v2 pin mapping
#define SDA_PIN 9
#define SCL_PIN 8
#define INT_PIN 7
#define TP_EN 6  // TouchPad ENABLE

uint8_t reportBuf[128];
const unsigned long IDLE_SLEEP_MS = 60000;

enum {
  RID_MOUSE = 1,
  RID_KEYBOARD = 2,
};

Adafruit_USBD_HID usb_hid;

uint8_t const hid_report_descriptor[] = {
  TUD_HID_REPORT_DESC_MOUSE(HID_REPORT_ID(RID_MOUSE)),
  TUD_HID_REPORT_DESC_KEYBOARD(HID_REPORT_ID(RID_KEYBOARD))
};

// Minimal HID keycodes used by defaults, defined here to avoid core-specific headers.
#ifndef KEYBOARD_MODIFIER_LEFTALT
#define KEYBOARD_MODIFIER_LEFTALT 0x04
#endif
#ifndef HID_KEY_ARROW_LEFT
#define HID_KEY_ARROW_LEFT 0x50
#endif
#ifndef HID_KEY_ARROW_RIGHT
#define HID_KEY_ARROW_RIGHT 0x4F
#endif
#ifndef MOUSE_BUTTON_LEFT
#define MOUSE_BUTTON_LEFT 0x01
#define MOUSE_BUTTON_RIGHT 0x02
#endif

BLEDis bledis;
BLEHidAdafruit blehid;
BLEBas blebas;
using namespace Adafruit_LittleFS_Namespace;

// SoftDevice connection config (increase HVN queue to reduce notify blocking)
static const uint16_t kBleMtuMax = BLE_GATT_ATT_MTU_DEFAULT;
static const uint16_t kBleEventLen = BLE_GAP_EVENT_LENGTH_DEFAULT;
static const uint8_t kBleHvnQueueSize = 6;
static const uint8_t kBleWrCmdQueueSize = 4;

void onConnect(uint16_t conn_handle);
void onDisconnect(uint16_t conn_handle, uint8_t reason);
void startAdv();
void enterDeepSleep();
void initStatusLed();
void setLedPatternActive();
void setLedPatternIdleLight();
void setLedPatternIdleMedium();
void setLedPatternOff();
void updateStatusLed(unsigned long now);

#if defined(ARDUINO_ARCH_NRF52)
extern const uint32_t g_ADigitalPinMap[];
#endif

static Print* cfgOut = &Serial;
static bool lastUsbMounted = false;
static bool lastBleConnected = false;
static bool waitFingerReleaseAfterReconnect = false;
static bool useBleWhenUsb = false;
static bool bleIdleSleepEnabled = false;
static unsigned long bleIdleLightMs = IDLE_SLEEP_MS * 10;
static unsigned long bleIdleMediumMs = IDLE_SLEEP_MS * 30;
static unsigned long bleIdleSleepMs = IDLE_SLEEP_MS * 60;
static uint32_t lightIdleReportIntervalMs = 33;
static uint16_t batteryMilliVolts = 0;
static uint8_t batteryPercent = 0;
static bool batteryReady = false;
static unsigned long lastBatterySampleMs = 0;
static const unsigned long kBatterySampleIntervalMs = 60000;

enum PowerStage {
  POWER_ACTIVE = 0,
  POWER_IDLE_LIGHT = 1,
  POWER_IDLE_MEDIUM = 2,
};

static PowerStage powerStage = POWER_ACTIVE;
static bool advSuppressedByIdle = false;

enum LedPattern {
  LED_PATTERN_OFF = 0,
  LED_PATTERN_ACTIVE_HOLD = 1,
  LED_PATTERN_IDLE_LIGHT = 2,
  LED_PATTERN_IDLE_MEDIUM = 3,
};

static LedPattern ledPattern = LED_PATTERN_OFF;
static unsigned long ledPatternStartMs = 0;
static bool ledStateOn = false;

#if defined(LED_STATE_ON)
static const uint8_t kLedOnLevel = LED_STATE_ON;
#else
static const uint8_t kLedOnLevel = HIGH;
#endif
static const uint8_t kLedOffLevel = (kLedOnLevel == HIGH) ? LOW : HIGH;

bool isUsbMounted() {
  return TinyUSBDevice.mounted();
}

bool useBleTransport() {
  return !isUsbMounted() || useBleWhenUsb;
}

void normalizeIdleThresholds();
uint32_t effectiveReportIntervalMs();
void leaveIdlePowerStage();
void resetGestureState();
void updateConnectionState();
void enterIdleLightStage();
void enterIdleMediumStage();
void handleIdlePower(unsigned long now);
void markActivity();
uint16_t readBatteryMilliVolts();
uint8_t batteryPercentFromMilliVolts(uint16_t mv);
void refreshBatteryStatus(bool forceNotify);
void handleBattery(unsigned long now);
void sendMouseMove(int8_t x, int8_t y);
void sendMouseMoveWithButtons(int8_t x, int8_t y, uint8_t buttons);
void sendMouseWheel(int8_t wheel);
void sendMouseButtons(uint8_t buttons);
void sendMouseClick(uint8_t buttons);
void sendKeyboard(uint8_t modifier, uint8_t keycode);
bool finalizeSingleTouch(unsigned long now, bool releasedByTimeout);
float applySingleFingerAxisResponse(int16_t delta, float axisScale);
float singleFingerAccelForSpeed(float speed);
float applyScrollAxisResponse(int16_t delta);
float scrollAccelForSpeed(float speed);
void handleReport(uint8_t* buf, uint16_t len);
bool waitIntRelease(unsigned long timeoutUs);
void readInputReport();

void writeStatusLed(bool on) {
  if (ledStateOn == on) return;
  ledStateOn = on;
  digitalWrite(LED_BUILTIN, on ? kLedOnLevel : kLedOffLevel);
}

void initStatusLed() {
  pinMode(LED_BUILTIN, OUTPUT);
  writeStatusLed(false);
  ledPattern = LED_PATTERN_OFF;
  ledPatternStartMs = millis();
}

void setLedPatternActive() {
  ledPattern = LED_PATTERN_ACTIVE_HOLD;
  ledPatternStartMs = millis();
  writeStatusLed(true);
}

void setLedPatternIdleLight() {
  ledPattern = LED_PATTERN_IDLE_LIGHT;
  ledPatternStartMs = millis();
}

void setLedPatternIdleMedium() {
  ledPattern = LED_PATTERN_IDLE_MEDIUM;
  ledPatternStartMs = millis();
}

void setLedPatternOff() {
  ledPattern = LED_PATTERN_OFF;
  ledPatternStartMs = millis();
  writeStatusLed(false);
}

void updateStatusLed(unsigned long now) {
  unsigned long phase;
  switch (ledPattern) {
    case LED_PATTERN_ACTIVE_HOLD:
      if (now - ledPatternStartMs < 1000) {
        writeStatusLed(true);
      } else {
        writeStatusLed(false);
      }
      break;
    case LED_PATTERN_IDLE_LIGHT:
      phase = (now - ledPatternStartMs) % 2000;
      writeStatusLed(phase < 60);
      break;
    case LED_PATTERN_IDLE_MEDIUM:
      phase = (now - ledPatternStartMs) % 4000;
      writeStatusLed((phase < 60) || (phase >= 240 && phase < 300));
      break;
    case LED_PATTERN_OFF:
    default:
      writeStatusLed(false);
      break;
  }
}

void rebootDevice() {
#if defined(ARDUINO_ARCH_NRF52)
  delay(20);
  NRF_POWER->GPREGRET = 0xB1;
  NVIC_SystemReset();
#endif
}
/*===== 参数配置区 =====*/
// 单指移动
float sensitivity = 0.3f;
float smoothFactor = 0.5f;
float accelFactor = 0.01f;
float maxAccel = 3.0f;
int16_t maxDelta = 60;
int16_t moveDeadband = 1;

// 双指滚动
float scrollSensitivity = 0.05f;
float scrollSmoothFactor = 0.2f;
bool naturalScroll = true;
const int16_t SCROLL_DEADBAND = 0;
float scrollLowSpeedBoostEnd = 0.35f;
float scrollMinActiveSpeed = 0.18f;
float scrollAccelStartSpeed = 0.45f;
float scrollAccelFactor = 0.90f;
float scrollMaxAccel = 2.50f;
const uint32_t SCROLL_REPORT_INTERVAL_MS = 8;
const float SCROLL_RELEASE_DECAY = 0.72f;
const float SCROLL_VELOCITY_EPSILON = 0.02f;
const float SCROLL_ACCUM_EPSILON = 0.02f;
const int8_t SCROLL_MAX_STEP_PER_REPORT = 1;

// 点击与释放
const unsigned long TAP_MAX_MS = 200;
const unsigned long LONG_PRESS_DRAG_MS = 220;
const unsigned long DOUBLE_TAP_WINDOW = 200;
const uint16_t DOUBLE_TAP_MAX_MOVE = 80;
const unsigned long RELEASE_TIMEOUT = 30;
const unsigned long INT_RELEASE_TIMEOUT_US = 5000;
const unsigned long TAP_GUARD_AFTER_SCROLL_MS = 150;
uint32_t reportIntervalMs = 8;
const float SINGLE_SOFT_DEADBAND_BLEND = 0.35f;
const float SINGLE_ACCEL_START_SPEED = 0.6f;
const float SINGLE_HOLD_DECAY = 0.65f;
const float SINGLE_VELOCITY_EPSILON = 0.01f;

// 三指滑动
uint16_t threeSwipeThresholdX = 200;
uint16_t threeSwipeThresholdY = 200;
uint16_t threeSwipeTimeout = 350;
uint16_t threeSwipeCooldown = 400;
// 四指滑动
uint16_t fourSwipeThresholdX = 200;
uint16_t fourSwipeThresholdY = 200;
uint16_t fourSwipeTimeout = 350;
uint16_t fourSwipeCooldown = 400;

const char* CONFIG_PATH = "/config.txt";

/*===== 状态 =====*/
enum GestureMode { MODE_NONE,
                   MODE_SINGLE,
                   MODE_DOUBLE,
                   MODE_TRIPLE,
                   MODE_QUAD };
GestureMode mode = MODE_NONE;

int16_t lastX1 = 0, lastY1 = 0;
int16_t lastX2 = 0, lastY2 = 0;
unsigned long lastTouchTime = 0;
unsigned long lastSwipeTime = 0;
unsigned long lastFourSwipeTime = 0;
unsigned long lastScrollTime = 0;
unsigned long lastScrollMotionTime = 0;
unsigned long lastActivityMs = 0;

int16_t tripleStartX = 0;
int16_t tripleStartY = 0;
int16_t tripleLastX = 0;
int16_t tripleLastY = 0;
unsigned long tripleStartTime = 0;
bool pendingThreeTap = false;
unsigned long lastThreeTapTime = 0;
int16_t lastThreeTapX = 0;
int16_t lastThreeTapY = 0;

int16_t quadStartX = 0;
int16_t quadStartY = 0;
int16_t quadLastX = 0;
int16_t quadLastY = 0;
unsigned long quadStartTime = 0;
bool pendingFourTap = false;
unsigned long lastFourTapTime = 0;
int16_t lastFourTapX = 0;
int16_t lastFourTapY = 0;

float smoothDx = 0, smoothDy = 0;
float accumX = 0, accumY = 0;
float velX = 0, velY = 0;
unsigned long lastReportMs = 0;

float smoothScroll = 0;
float accumScroll = 0;
float scrollVel = 0;
unsigned long lastScrollReportMs = 0;

bool tapCandidate = false;
bool dragActive = false;
unsigned long tapStartTime = 0;
int16_t tapStartX = 0;
int16_t tapStartY = 0;
bool pendingClick = false;
unsigned long lastTapTime = 0;
int16_t lastTapX = 0;
int16_t lastTapY = 0;

float applySingleFingerAxisResponse(int16_t delta, float axisScale) {
  float scaled = delta * sensitivity * axisScale;
  float magnitude = abs(scaled);
  if (magnitude <= 0.0f) return 0.0f;

  float softDeadband = moveDeadband * sensitivity * axisScale;
  float response = magnitude;
  if (softDeadband > 0.0f) {
    if (magnitude <= softDeadband) {
      response = magnitude * SINGLE_SOFT_DEADBAND_BLEND;
    } else {
      response = (softDeadband * SINGLE_SOFT_DEADBAND_BLEND) + (magnitude - softDeadband);
    }
  }

  return scaled < 0.0f ? -response : response;
}

float singleFingerAccelForSpeed(float speed) {
  float totalMaxAccel = max(1.0f, maxAccel);
  if (speed <= SINGLE_ACCEL_START_SPEED) return 1.0f;

  float extraSpeed = speed - SINGLE_ACCEL_START_SPEED;
  float extraAccel = min(extraSpeed * accelFactor, totalMaxAccel - 1.0f);
  return 1.0f + extraAccel;
}

float applyScrollAxisResponse(int16_t delta) {
  float scaled = delta * scrollSensitivity;
  float magnitude = abs(scaled);
  if (magnitude <= 0.0f) return 0.0f;

  float response = magnitude;
  if (magnitude < scrollLowSpeedBoostEnd) {
    float t = magnitude / scrollLowSpeedBoostEnd;
    response = scrollMinActiveSpeed + (magnitude - scrollMinActiveSpeed) * t;
  }

  return scaled < 0.0f ? -response : response;
}

float scrollAccelForSpeed(float speed) {
  float totalMaxAccel = max(1.0f, scrollMaxAccel);
  if (speed <= scrollAccelStartSpeed) return 1.0f;

  float extraSpeed = speed - scrollAccelStartSpeed;
  float extraAccel = min(extraSpeed * scrollAccelFactor, totalMaxAccel - 1.0f);
  return 1.0f + extraAccel;
}

// 触摸板区域（基于实测坐标范围）
const int16_t TOUCH_MAX_X = 2628;
const int16_t TOUCH_MAX_Y = 1332;
uint8_t TOP_ZONE_PERCENT = 20;
uint8_t SIDE_ZONE_PERCENT = 35;
const float AXIS_SCALE_X = 1.0f;
const float AXIS_SCALE_Y = 1.0f;

bool enableNavZones = true;
ZoneBinding leftTopZone = { ZONE_KEYBOARD, 0, KEYBOARD_MODIFIER_LEFTALT, HID_KEY_ARROW_LEFT };
ZoneBinding rightTopZone = { ZONE_KEYBOARD, 0, KEYBOARD_MODIFIER_LEFTALT, HID_KEY_ARROW_RIGHT };
ZoneBinding rightBottomZone = { ZONE_MOUSE, MOUSE_BUTTON_RIGHT, 0, 0 };
ZoneBinding leftBottomZone = { ZONE_NONE, 0, 0, 0 };

ZoneBinding threeLeftBinding = { ZONE_NONE, 0, 0, 0 };
ZoneBinding threeRightBinding = { ZONE_NONE, 0, 0, 0 };
ZoneBinding threeUpBinding = { ZONE_NONE, 0, 0, 0 };
ZoneBinding threeDownBinding = { ZONE_NONE, 0, 0, 0 };
ZoneBinding threeTapBinding = { ZONE_NONE, 0, 0, 0 };
ZoneBinding threeDoubleTapBinding = { ZONE_NONE, 0, 0, 0 };
ZoneBinding fourLeftBinding = { ZONE_NONE, 0, 0, 0 };
ZoneBinding fourRightBinding = { ZONE_NONE, 0, 0, 0 };
ZoneBinding fourUpBinding = { ZONE_NONE, 0, 0, 0 };
ZoneBinding fourDownBinding = { ZONE_NONE, 0, 0, 0 };
ZoneBinding fourTapBinding = { ZONE_NONE, 0, 0, 0 };
ZoneBinding fourDoubleTapBinding = { ZONE_NONE, 0, 0, 0 };

void resetGestureState() {
  unsigned long now = millis();
  mode = MODE_NONE;
  lastX1 = lastY1 = 0;
  lastX2 = lastY2 = 0;
  lastTouchTime = now;
  lastScrollTime = now;
  lastScrollMotionTime = 0;

  tripleStartX = tripleStartY = 0;
  tripleLastX = tripleLastY = 0;
  tripleStartTime = 0;
  pendingThreeTap = false;
  lastThreeTapTime = 0;
  lastThreeTapX = lastThreeTapY = 0;

  quadStartX = quadStartY = 0;
  quadLastX = quadLastY = 0;
  quadStartTime = 0;
  pendingFourTap = false;
  lastFourTapTime = 0;
  lastFourTapX = lastFourTapY = 0;

  smoothDx = smoothDy = 0;
  accumX = accumY = 0;
  velX = velY = 0;
  lastReportMs = now;

  smoothScroll = 0;
  accumScroll = 0;
  scrollVel = 0;
  lastScrollReportMs = now;

  tapCandidate = false;
  dragActive = false;
  tapStartTime = 0;
  tapStartX = tapStartY = 0;
  pendingClick = false;
  lastTapTime = 0;
  lastTapX = lastTapY = 0;
}

#include "modules/touchpad_slot_manager.h"
#include "modules/touchpad_power_battery.h"

void applyDefaults() {
  sensitivity = 0.3f;
  smoothFactor = 0.5f;
  accelFactor = 0.01f;
  maxAccel = 3.0f;
  maxDelta = 60;
  moveDeadband = 1;
  scrollSensitivity = 0.05f;
  scrollLowSpeedBoostEnd = 0.35f;
  scrollMinActiveSpeed = 0.18f;
  scrollAccelStartSpeed = 0.45f;
  scrollAccelFactor = 0.90f;
  scrollMaxAccel = 2.50f;
  TOP_ZONE_PERCENT = 20;
  SIDE_ZONE_PERCENT = 35;
  enableNavZones = true;
  useBleWhenUsb = false;
  bleIdleSleepEnabled = false;
  bleIdleLightMs = IDLE_SLEEP_MS * 10;
  bleIdleMediumMs = IDLE_SLEEP_MS * 30;
  bleIdleSleepMs = IDLE_SLEEP_MS * 60;
  lightIdleReportIntervalMs = 33;
  reportIntervalMs = 8;
  leftTopZone = { ZONE_KEYBOARD, 0, KEYBOARD_MODIFIER_LEFTALT, HID_KEY_ARROW_LEFT };
  rightTopZone = { ZONE_KEYBOARD, 0, KEYBOARD_MODIFIER_LEFTALT, HID_KEY_ARROW_RIGHT };
  rightBottomZone = { ZONE_MOUSE, MOUSE_BUTTON_RIGHT, 0, 0 };
  leftBottomZone = { ZONE_NONE, 0, 0, 0 };
  threeSwipeThresholdX = 200;
  threeSwipeThresholdY = 200;
  threeSwipeTimeout = 350;
  threeSwipeCooldown = 400;
  fourSwipeThresholdX = 200;
  fourSwipeThresholdY = 200;
  fourSwipeTimeout = 350;
  fourSwipeCooldown = 400;
  threeLeftBinding = { ZONE_NONE, 0, 0, 0 };
  threeRightBinding = { ZONE_NONE, 0, 0, 0 };
  threeUpBinding = { ZONE_NONE, 0, 0, 0 };
  threeDownBinding = { ZONE_NONE, 0, 0, 0 };
  threeTapBinding = { ZONE_NONE, 0, 0, 0 };
  threeDoubleTapBinding = { ZONE_NONE, 0, 0, 0 };
  fourLeftBinding = { ZONE_NONE, 0, 0, 0 };
  fourRightBinding = { ZONE_NONE, 0, 0, 0 };
  fourUpBinding = { ZONE_NONE, 0, 0, 0 };
  fourDownBinding = { ZONE_NONE, 0, 0, 0 };
  fourTapBinding = { ZONE_NONE, 0, 0, 0 };
  fourDoubleTapBinding = { ZONE_NONE, 0, 0, 0 };
  pendingClick = false;
  pendingThreeTap = false;
  pendingFourTap = false;
  slotManagerEnabled = false;
  slotResetAll();
  normalizeIdleThresholds();
}

/*===========================
   冷启动 Enable 时序
   ===========================*/
void touchColdBoot() {
  pinMode(TP_EN, OUTPUT);

  digitalWrite(TP_EN, LOW);  // Disable
  delay(20);

  digitalWrite(TP_EN, HIGH);  // Enable（关键上升沿）
  delay(150);                 // 等触摸 IC 完全启动
}

void initI2C() {
#if defined(ARDUINO_ARCH_NRF52)
  Wire.setPins(SDA_PIN, SCL_PIN);
#else
  Wire.setSDA(SDA_PIN);
  Wire.setSCL(SCL_PIN);
#endif
  Wire.begin();
  Wire.setClock(400000);
  delay(50);
}

void initUsbHid() {
  if (!TinyUSBDevice.isInitialized()) {
    TinyUSBDevice.begin(0);
  }
  usb_hid.setReportDescriptor(hid_report_descriptor,
                              sizeof(hid_report_descriptor));
  usb_hid.begin();
  if (TinyUSBDevice.mounted()) {
    TinyUSBDevice.detach();
    delay(10);
    TinyUSBDevice.attach();
  }
}

#include "modules/touchpad_ble_transport.h"

void enterDeepSleep() {
#if defined(ARDUINO_ARCH_NRF52)
  setLedPatternOff();
  for (uint8_t i = 0; i < 3; i++) {
    writeStatusLed(true);
    delay(80);
    writeStatusLed(false);
    delay(80);
  }
  if (Bluefruit.connected()) {
    Bluefruit.disconnect(0);
    delay(200);
  }
  Bluefruit.Advertising.stop();

  uint32_t wake_pin = g_ADigitalPinMap[INT_PIN];
  nrf_gpio_cfg_sense_input(wake_pin, NRF_GPIO_PIN_PULLUP, NRF_GPIO_PIN_SENSE_LOW);
  delay(5);
  NRF_POWER->SYSTEMOFF = 1;
  while (true) {
    __WFE();
  }
#endif
}

void onConnect(uint16_t conn_handle) {
  markActivity();
  BLEConnection* connection = Bluefruit.Connection(conn_handle);
  if (connection) {
    connection->requestConnectionParameter(12, 0, 400);
  }
  slotOnConnect(conn_handle);
}

void onDisconnect(uint16_t conn_handle, uint8_t reason) {
  (void)conn_handle;
  (void)reason;
  slotOnDisconnect();
  if (advSuppressedByIdle) {
    Bluefruit.Advertising.stop();
  }
}
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
void loop() {
  handleSerial();
  updateTransport();
  updateConnectionState();
  if (digitalRead(INT_PIN) == LOW) {
    readInputReport();
  }
  unsigned long now = millis();
  handleBattery(now);
  updateStatusLed(now);
  handleIdlePower(now);
  now = millis();
  updateStatusLed(now);

  /*单指超时释放*/
  if (mode == MODE_SINGLE && now - lastTouchTime > RELEASE_TIMEOUT) {
    finalizeSingleTouch(now, true);
  }

  /*双指超时释放*/
  if (mode == MODE_DOUBLE && now - lastTouchTime > RELEASE_TIMEOUT) {
    mode = MODE_NONE;
    lastScrollTime = now;
  }

  if (mode == MODE_TRIPLE && now - lastTouchTime > RELEASE_TIMEOUT) {
    mode = MODE_NONE;
  }
  if (mode == MODE_QUAD && now - lastTouchTime > RELEASE_TIMEOUT) {
    mode = MODE_NONE;
  }

  /*连续输出*/
  if (mode == MODE_SINGLE && (!tapCandidate || dragActive)) {
    uint32_t intervalMs = effectiveReportIntervalMs();
    if (now - lastReportMs >= intervalMs) {
      unsigned long dtMs = now - lastReportMs;
      lastReportMs = now;
      float dt = dtMs / (float)intervalMs;
      if (dt > 1.5f) dt = 1.0f;
      accumX += velX * dt;
      accumY += velY * dt;
      int16_t mx16 = (int16_t)accumX;
      int16_t my16 = (int16_t)accumY;
      mx16 = constrain(mx16, -127, 127);
      my16 = constrain(my16, -127, 127);
      int8_t mx = (int8_t)mx16;
      int8_t my = (int8_t)my16;
      if (mx || my) {
        if (dragActive) {
          sendMouseMoveWithButtons(mx, my, MOUSE_BUTTON_LEFT);
        } else {
          sendMouseMove(mx, my);
        }
        accumX -= mx;
        accumY -= my;
      }
    }
  }

  bool scrollActive = (mode == MODE_DOUBLE) || (abs(scrollVel) > SCROLL_VELOCITY_EPSILON) || (abs(accumScroll) > 1.0f);
  if (scrollActive && now - lastScrollReportMs >= SCROLL_REPORT_INTERVAL_MS) {
    unsigned long dtMs = now - lastScrollReportMs;
    lastScrollReportMs = now;
    float dt = dtMs / (float)SCROLL_REPORT_INTERVAL_MS;
    if (dt > 2.0f) dt = 2.0f;

    if (mode != MODE_DOUBLE) {
      scrollVel *= SCROLL_RELEASE_DECAY;
      smoothScroll *= SCROLL_RELEASE_DECAY;
      if (abs(scrollVel) < SCROLL_VELOCITY_EPSILON) scrollVel = 0;
      if (abs(smoothScroll) < SCROLL_VELOCITY_EPSILON) smoothScroll = 0;
    }

    accumScroll += scrollVel * dt;

    int8_t s = 0;
    if (accumScroll >= 1.0f) {
      s = SCROLL_MAX_STEP_PER_REPORT;
    } else if (accumScroll <= -1.0f) {
      s = -SCROLL_MAX_STEP_PER_REPORT;
    }

    if (s) {
      sendMouseWheel(naturalScroll ? s : -s);
      accumScroll -= s;
      lastScrollMotionTime = now;
    } else if (mode != MODE_DOUBLE && abs(accumScroll) < SCROLL_ACCUM_EPSILON) {
      accumScroll = 0;
    }
  }

  if (pendingClick && now - lastTapTime > DOUBLE_TAP_WINDOW) {
    sendMouseClick(MOUSE_BUTTON_LEFT);
    pendingClick = false;
  }
  if (pendingThreeTap && now - lastThreeTapTime > DOUBLE_TAP_WINDOW) {
    performZoneAction(threeTapBinding);
    pendingThreeTap = false;
  }
  if (pendingFourTap && now - lastFourTapTime > DOUBLE_TAP_WINDOW) {
    performZoneAction(fourTapBinding);
    pendingFourTap = false;
  }
}

void handleSerial() {
  static String line;
  while (Serial.available()) {
    char c = (char)Serial.read();
    if (c == '\n') {
      line.trim();
      if (line.length() > 0) {
        processCommand(line);
      }
      line = "";
    } else if (c != '\r') {
      line += c;
    }
  }
}

void processCommand(const String& line) {
  markActivity();

  if (line.equalsIgnoreCase("HELP")) {
    cfgOut->println("CMD: GET scrollSensitivity");
    cfgOut->println("CMD: GET");
    cfgOut->println("CMD: SET <key> <value>");
    cfgOut->println("CMD: SAVE");
    cfgOut->println("CMD: LOAD");
    cfgOut->println("CMD: RESET");
    cfgOut->println("CMD: BOOT");
    cfgOut->println("CMD: INFO SLOT");
    cfgOut->println("CMD: PAIRCLR");
    cfgOut->println("CMD: SLOT <1|2|3>");
    cfgOut->println("CMD: PAIR SLOT <1|2|3>");
    cfgOut->println("CMD: PAIR SLOT <1|2|3> FORCE");
    cfgOut->println("CMD: UNPAIR SLOT <1|2|3>");
    cfgOut->println("CMD: GET useBleWhenUsb");
    cfgOut->println("CMD: GET bleIdleSleepEnabled");
    cfgOut->println("CMD: GET slotManagerEnabled");
    cfgOut->println("CMD: GET slot");
    cfgOut->println("CMD: GET bleIdleLightMs");
    cfgOut->println("CMD: GET bleIdleMediumMs");
    cfgOut->println("CMD: GET bleIdleSleepMs");
    cfgOut->println("CMD: GET lightIdleRate");
    cfgOut->println("CMD: GET scrollLowSpeedBoostEnd");
    cfgOut->println("CMD: GET scrollMinActiveSpeed");
    cfgOut->println("CMD: GET scrollAccelStartSpeed");
    cfgOut->println("CMD: GET scrollAccelFactor");
    cfgOut->println("CMD: GET scrollMaxAccel");
    cfgOut->println("CMD: GET battery");
    return;
  }

  if (line.startsWith("RATE ")) {
    int v = line.substring(5).toInt();
    if (v >= 10 && v <= 200) {
      reportIntervalMs = (uint32_t)(1000 / v);
      if (reportIntervalMs == 0) reportIntervalMs = 1;
      normalizeIdleThresholds();
    }
    return;
  }
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

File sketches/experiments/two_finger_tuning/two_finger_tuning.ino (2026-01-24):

#include <Wire.h>
#include <Mouse.h>

/* ===== I2C-HID 固定参数 ===== */
#define I2C_ADDR 0x2C  // 你的触摸板地址
#define INPUT_REG_L 0x09
#define INPUT_REG_H 0x01

/* ===== INT 引脚 ===== */
#define INT_PIN 10  // GP10，根据你实际修改

/* ===== 缓冲区 ===== */
uint8_t reportBuf[180];

bool lastTouching = false;
int16_t lastX = 0;
int16_t lastY = 0;
unsigned long lastReportTime = 0;
const unsigned long TOUCH_RELEASE_TIMEOUT = 15;  // ms

/* ======= 优化移动卡顿 ========= */
// 灵敏度（0.1 ~ 1.0 之间调）
float sensitivity = 0.3f;

// 平滑系数（越小越平滑，0.2 ~ 0.4 推荐）
float smoothFactor = 0.2f;

// 最大单次移动，防止跳变
const int16_t MAX_DELTA = 30;

// 加速参数
float accelFactor = 0.015f;  // 速度相关加速
float maxAccel = 2.5f;

// 平滑后的速度
float smoothDx = 0;
float smoothDy = 0;

// 亚像素累积
float accumX = 0;
float accumY = 0;

float currentVelX = 0;
float currentVelY = 0;
unsigned long lastMoveTime = 0;

/* ===== 双指滚动参数 ===== */
const unsigned long TWO_FINGER_RELEASE_TIMEOUT = 15;  // ms

float scrollSensitivity = 0.25f;
float scrollSmoothFactor = 0.25f;
float scrollAccelFactor = 0.02f;
float maxScrollAccel = 2.0f;

float smoothScroll = 0;
float accumScroll = 0;
float currentScrollVel = 0;

int16_t lastY1 = 0;
int16_t lastY2 = 0;

bool lastTwoFinger = false;


void setup() {
  Serial.begin(115200);
  while (!Serial) {}

  Wire.begin();
  Wire.setClock(400000);

  pinMode(INT_PIN, INPUT_PULLUP);

  Mouse.begin();

  Serial.println("Ready");
}

void handleTouchToMouse(uint8_t* buf, uint16_t len) {
  if (len < 12) return;
  if (buf[2] != 0x04) return;

  bool finger1 = buf[3] & 0x01;
  bool finger2 = buf[3] & 0x02;

  Serial.print("buf[3] is ");
  Serial.println(buf[3]);

  unsigned long now = millis();

  /* =========================
     ===== 双指滚动模式 =====
     ========================= */
  if (finger1 && finger2) {
    lastReportTime = now;
    //Serial.println("TwoFinger Mode");
    int16_t y1 = buf[6] | (buf[7] << 8);
    int16_t y2 = buf[10] | (buf[11] << 8);

    if (lastTwoFinger) {
      int16_t rawDy1 = y1 - lastY1;
      int16_t rawDy2 = y2 - lastY2;
      int16_t rawDy = (rawDy1 + rawDy2) / 2;

      rawDy = constrain(rawDy, -MAX_DELTA, MAX_DELTA);

      float dy = rawDy * scrollSensitivity;

      float speed = abs(dy);
      float accel = 1.0f + min(speed * scrollAccelFactor, maxScrollAccel);
      dy *= accel;

      smoothScroll += (dy - smoothScroll) * scrollSmoothFactor;
      currentScrollVel = smoothScroll;
    } else {
      smoothScroll = 0;
      accumScroll = 0;
    }

    lastY1 = y1;
    lastY2 = y2;

    lastTwoFinger = true;
    lastTouching = false;  // 🔴 关键：禁止单指逻辑
    return;
  }

  /* =========================
     ===== 单指移动模式 =====
     ========================= */
  lastTwoFinger = false;

  if (finger1) {
    lastReportTime = now;
    //Serial.println("OneFinger Mode");
    int16_t x = buf[4] | (buf[5] << 8);
    int16_t y = buf[6] | (buf[7] << 8);

    if (lastTouching) {
      int16_t rawDx = x - lastX;
      int16_t rawDy = y - lastY;

      rawDx = constrain(rawDx, -MAX_DELTA, MAX_DELTA);
      rawDy = constrain(rawDy, -MAX_DELTA, MAX_DELTA);

      float dx = rawDx * sensitivity;
      float dy = rawDy * sensitivity;

      float speed = sqrt(dx * dx + dy * dy);
      float accel = 1.0f + min(speed * accelFactor, maxAccel);
      dx *= accel;
      dy *= accel;

      smoothDx += (dx - smoothDx) * smoothFactor;
      smoothDy += (dy - smoothDy) * smoothFactor;

      currentVelX = smoothDx;
      currentVelY = smoothDy;
    } else {
      smoothDx = smoothDy = 0;
      accumX = accumY = 0;
    }

    lastX = x;
    lastY = y;
    lastTouching = true;
  }
}




void loop() {
  if (digitalRead(INT_PIN) == LOW) {
    readInputReport();
  }

  /* ===== 单指释放 ===== */
  if (lastTouching && (millis() - lastReportTime > TOUCH_RELEASE_TIMEOUT)) {
    lastTouching = false;
    currentVelX = 0;
    currentVelY = 0;
  }

  /* ===== 双指释放 ===== */
  if (lastTwoFinger && (millis() - lastReportTime > TWO_FINGER_RELEASE_TIMEOUT)) {
    lastTwoFinger = false;
    currentScrollVel = 0;
    smoothScroll = 0;
    accumScroll = 0;
  }

  /* ===== 单指输出 ===== */
  if (lastTouching) {
    accumX += currentVelX;
    accumY += currentVelY;
    int8_t moveX = (int8_t)accumX;
    int8_t moveY = (int8_t)accumY;
    if (moveX || moveY) {
      Mouse.move(moveX, moveY);
      accumX -= moveX;
      accumY -= moveY;
    }
  }

  /* ===== 双指滚动输出 ===== */
  if (lastTwoFinger) {
    accumScroll += currentScrollVel;
    int8_t scroll = (int8_t)accumScroll;
    if (scroll) {
      Mouse.move(0, 0, -scroll);
      accumScroll -= scroll;
    }
  }
}


/* =============================
 *  严格的一次性 Input Report 读取
 * ============================= */
void readInputReport() {
  // 1. 指向 Input Register
  Wire.beginTransmission(I2C_ADDR);
  Wire.write(INPUT_REG_L);
  Wire.write(INPUT_REG_H);
  if (Wire.endTransmission(false) != 0) {
    Serial.println("I2C set reg failed");
    return;
  }

  // 2. 先读前 2 字节（Report Length）
  if (Wire.requestFrom(I2C_ADDR, (uint8_t)2) != 2) {
    Serial.println("Length read failed");
    return;
  }

  uint16_t len = Wire.read();
  len |= (Wire.read() << 8);

  if (len == 0 || len > sizeof(reportBuf)) {
    Serial.print("Invalid report length: ");
    Serial.println(len);
    return;
  }

  // 3. 再读完整 Report
  if (Wire.requestFrom(I2C_ADDR, (uint8_t)len) != len) {
    Serial.println("Report read failed");
    return;
  }

  for (uint16_t i = 0; i < len; i++) {
    reportBuf[i] = Wire.read();
  }

  // 4. 打印（盲读）
  Serial.print("REPORT (");
  Serial.print(len);
  Serial.print("): ");

  for (uint16_t i = 0; i < len; i++) {
    if (reportBuf[i] < 0x10) Serial.print("0");
    Serial.print(reportBuf[i], HEX);
    Serial.print(" ");
  }
  Serial.println();

  handleTouchToMouse(reportBuf, len);

  // 5. 等待 INT 释放（非常重要，防止重复读）
  while (digitalRead(INT_PIN) == LOW) {
    delayMicroseconds(50);
  }
}

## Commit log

2026-01-24 完善触摸板逻辑与使用说明
2026-01-24 调整双击窗口时间
2026-01-24 移除点击位移阈值
2026-01-25 修复双击触发间隔
2026-01-25 调整双击窗口
2026-01-25 降低双指滚动灵敏度
2026-01-25 调整双指滚动加速曲线
2026-01-25 简化双指滚动到线性映射
2026-01-25 进一步降低双指滚动灵敏度
2026-01-25 切换为自然滚动方向
2026-01-25 增加滚动方向参数
2026-01-25 补充滚动方向说明
2026-01-25 停止手指静止时的惯性
2026-01-25 增加双击距离阈值
2026-01-25 补充双击距离参数说明
2026-01-25 记录触摸板坐标范围
2026-01-25 增加前进后退触摸区域
2026-01-25 完善触摸区域说明
2026-01-25 切换到TinyUSB复合HID
2026-01-25 移除音量控制逻辑
2026-01-25 扩大左右触摸区域宽度
2026-01-25 增加串口参数配置
2026-01-25 增加串口配置工具
2026-01-25 增加左下角区域动作
2026-01-25 扩展串口配置区域参数
2026-01-25 增加配置重置命令
2026-01-25 增加配置界面工具
2026-01-25 补充UI安装步骤
2026-01-25 添加UI启动脚本
2026-01-25 添加桌面启动器
2026-01-25 支持区域按键绑定
2026-01-25 优化UI录制交互
2026-01-25 改进快捷键录制
2026-01-25 优化UI滚动布局
2026-01-25 优化快捷键录制窗口
2026-01-25 增加三指上下滑动
2026-01-26 Split touchpad sketch by board
2026-01-26 Track nrf migration status
2026-01-26 Add ble uart config channel
2026-01-27 Prevent tap jitter from moving cursor
    [touchpad_hid_nrf.ino]
2026-01-27 Add BOOTSEL command and UI button
2026-01-27 Relax tap jitter cancellation
    [touchpad_hid_nrf.ino]
2026-01-31 Add touchpad case assets and update BLE test
    [touchpad_case.scad, touchpad_case.stl]
2026-01-31 Add nice!nano workflows and probe sketches
    [daplink_nrf52.cfg, jlink_nrf52.cfg]
2026-02-01 Add power saving note to bluetooth migration
2026-02-01 Note BLED red LED control
2026-02-01 Add soft switch test and reference images
2026-02-02 Move 3D models into models directory
    [touchpad_case.scad, touchpad_case.stl]
2026-02-02 Document sleep power strategy
2026-02-02 Note battery strategy deferred
2026-02-03 Update USB opening size for case
    [touchpad_case.scad, touchpad_case.stl]
2026-02-04 Expand case outer size to 117x69
    [touchpad_case.scad, touchpad_case.stl]
2026-02-04 Adjust case outer expansion to 1mm
    [touchpad_case.scad, touchpad_case.stl]
2026-02-04 Add USB/BLE auto transport switching
2026-02-05 Stabilize HID report rate
    [touchpad_hid_nrf.ino]
2026-02-05 Add UF2 tools and stabilize nRF touchpad boot
    [touchpad_hid_nrf.ino]
2026-02-05 Remove diagnostics and fix TinyUSB init
    [touchpad_hid_nrf.ino]
2026-02-05 Clamp USB report deltas
2026-02-06 Clamp first-frame motion after idle
2026-02-06 规范：日志与提交信息使用中文
2026-02-07 更新BLE HID速率测试与输入统计脚本
2026-02-07 提交BLE HID速率测试构建产物
2026-02-07 更新NRF触摸板速率统计日志
2026-02-07 移除日志并支持串口调频
2026-02-07 默认USB连接时使用USB模式
2026-02-07 UI增加上报频率配置
2026-02-07 修复InternalFS挂载与删除桌面入口
2026-02-07 保存并回显上报频率
2026-02-07 更新单指默认参数
2026-02-07 添加广播名称与清配对命令
2026-02-07 添加睡眠触发时长配置
2026-02-07 删除 pico 目录下不再使用的草图与头文件
2026-02-08 增加三阶段省电策略并同步UI配置项
2026-02-08 增加省电阶段红灯状态指示
2026-02-08 更新文档并同步当前 nRF 开发与烧录流程
2026-02-08 添加 README 同步脚本并生成 README
2026-02-08 添加可共享的 pre-commit 钩子配置
2026-02-08 移除项目中 Pico 相关残留内容
2026-02-08 补充 BOM 文档并添加触摸板关键词备注
2026-02-08 完善 BOM 清单并补充 FPC 相关项
2026-02-08 更新模型备注并说明空间冗余
2026-02-08 调整 USB 开口尺寸并更新外壳模型导出
    [touchpad_case.scad, touchpad_case.stl]
2026-02-08 新增介绍视频流程文档并更新索引
2026-02-08 新增三指点击与四指手势并同步配置界面
2026-02-08 更新BOM与接线说明并移除UI引导BOOT按钮
2026-02-08 修正文档边界并保留fpc_pinout仅含FPC定义
2026-02-08 修正BOM中微动尺寸的Markdown显示
2026-02-08 补充FPC软排线同向6P备注
2026-02-08 补充触摸板三阶段省电策略说明
2026-02-09 修复重连后单指误判双指问题
2026-02-09 添加 Product-TouchPad 子模块关联
2026-02-09 同步子模块并提交当前本地改动
2026-02-09 更新 Product-TouchPad 子模块指针
2026-02-09 更新子模块：补充EDA流程文档
2026-02-09 更新 touchpad_hid_nrf 编译产物
2026-02-10 修复nRFCrypto预编译库缺失导致的编译失败
2026-02-10 更新touchpad_hid_nrf编译产物UF2
2026-02-10 更新子模块指向并保存嘉立创库版本
2026-02-10 同步SDA/SCL引脚映射并更新文档
2026-02-10 调整触摸板引脚映射并同步文档
2026-02-10 交换I2C引脚D8与D9并同步文档
2026-02-12 新增蓝牙电量上报与串口电量查询
2026-02-12 更新Product-TouchPad子模块版本
2026-02-12 新增BLE三设备切换实现方案文档
2026-02-12 移除Product-TouchPad子模块并并入主仓库
2026-02-12 重构目录结构并迁移制造资料到主仓库
2026-02-12 更新微动开关规格并补充提交后默认推送规范
2026-02-12 新增槽位信息命令与覆盖确认机制
2026-02-12 补充热熔螺母安装与3D开孔设计说明
2026-03-01 修复模块包含并记录FPC转接方向问题
2026-03-01 新增后续硬件优化清单文档
2026-03-01 更新FPC反转定义并补充底板同步调整
2026-03-09 添加外壳与PCB模型文件
    [外壳.FCStd]
2026-03-09 更新外壳模型与备份文件
    [外壳-盒体.stl, 外壳.FCStd]
2026-03-09 更新FreeCAD外壳模型文件
2026-03-09 修改孔位置
    [外壳.FCStd]
2026-03-09 更新外壳FreeCAD模型
    [外壳.FCStd]
2026-03-09 调整外壳斜面模型
    [外壳-盒体.stl, 外壳.FCStd]
2026-03-10 调整外壳斜面切刀前侧厚度到5mm
    [外壳.FCStd]
2026-03-11 补充Windows配置工具打包发布流程
2026-03-11 优化双指滚动平滑释放
2026-03-11 提交最新UF2构建产物
2026-03-11 改为单指长按触发拖动
2026-03-11 调整默认滚动灵敏度
2026-03-13 优化单指移动低速平滑与高速加速
2026-03-13 优化省电活动判定与空闲等待
2026-03-13 修复省电优化引入的编译问题
2026-03-13 提交最新触摸板 UF2 固件
2026-03-13 优化双指滚动低速与加速响应
2026-03-13 同步 UI 与滚动省电配置项
2026-03-13 修复滚动保护影响点击识别
2026-03-13 修复手势点击状态冲突
2026-03-13 修复单指手感调校影响点击判定
2026-03-14 更新外壳 FreeCAD 模型文件
    [外壳-盒体.stl, 外壳.FCStd]
2026-03-15 回退周五省电策略改动
2026-03-15 调整默认上报频率与省电时长
2026-03-15 提交模型与固件产物更新
    [外壳-盒体.stl, 外壳.FCStd]
2026-03-15 同步触摸模组引脚文档定义
2026-03-15 提交本地模型文件变更
    [touchpad_case.scad, touchpad_case.stl, 外壳-盒体.3mf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]
2026-03-15 提交 Gerber 生产文件
2026-03-15 更新 BOM 清单内容
2026-03-15 删除视频介绍流程文档
2026-03-16 补充V2介绍文档与BOM脚垫信息
2026-05-11 新增 Tauri 配置工具并打包 AppImage
2026-05-12 新增 ui_tauri 三平台自动发版工作流
2026-05-12 修复 ui_tauri 发版：构建前自动生成 tauri 图标
2026-05-12 修复 Windows 打包图标配置：显式使用 ico/icns
2026-05-12 修复 Linux 发版依赖：补充 libudev-dev 和 pkg-config
2026-05-12 删除本地编译产物与无用打包文件
2026-05-12 删除 Python 配置 UI，统一为 Tauri 方案
2026-05-12 新增 models 外壳文件
    [外壳-Body001.3mf, 外壳-Body001.stl]
